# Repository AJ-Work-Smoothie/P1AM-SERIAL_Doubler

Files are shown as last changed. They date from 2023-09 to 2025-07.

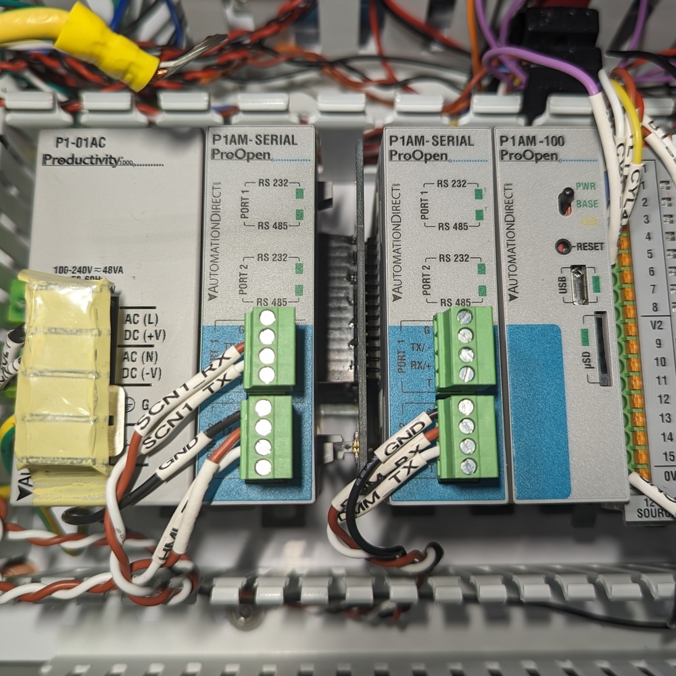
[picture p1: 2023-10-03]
img/Assy.jpg

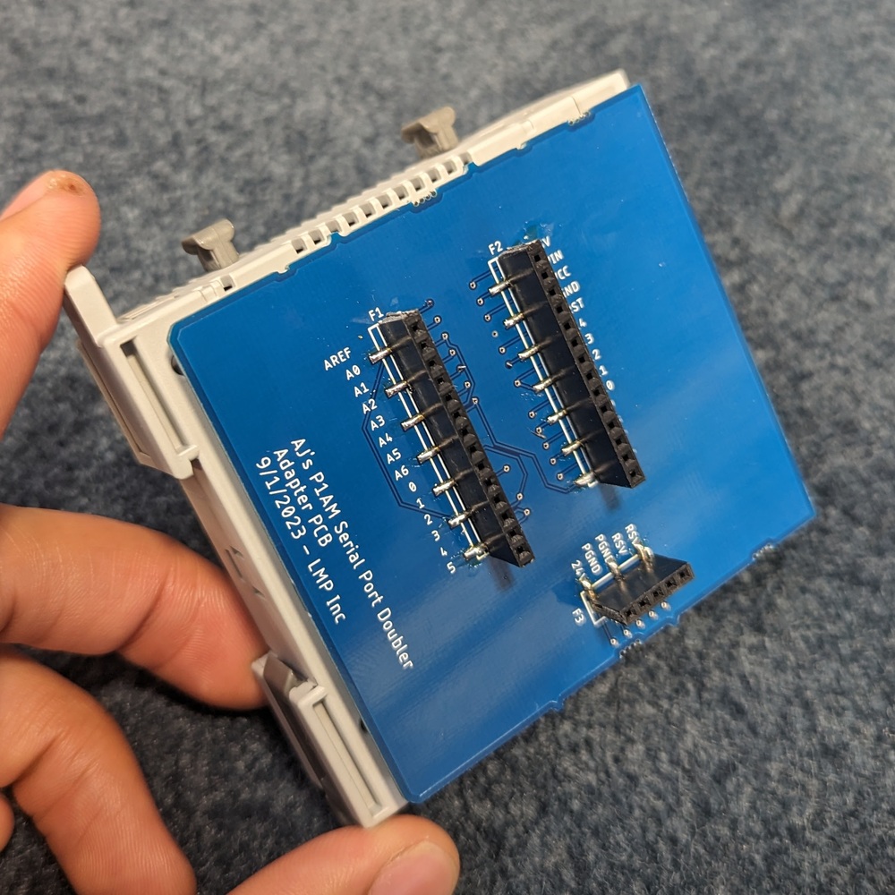
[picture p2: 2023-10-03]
img/Stacked.jpg

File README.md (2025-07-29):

# P1AM-SERIAL Doubler

Sometimes you just need more serial ports! Between modbus, SCPI, ASCII, and the hundred other protocols that work via RS232, sometimes you just can't combine different protocols and need more physical ports. Fear no more! I've done all of the heavy lifting for you. I've designed a circuit board and modified the code for this library to enable to usage of another P1AM-Serial module expanding the amount of ports from 2 to 4! See the wiki for photos.

### Under the Hood:
At its core, the P1AM is a SAMD21G18, which is the same IC that runs the Arduino Zero. If you check into the documentation for the SAMD21, you'll see that is has 6 "sercom" ports. In other words, it has 6 different ports that are configurable to be GPIO pins, UART, I2C, or SPI pins. What I've done is enabled an unsused port, and hijacked the I2C port and reconfigured it to be a serial UART port for us. All of this might sound quite scary, and honestly, it is. Good news is you can skip all the technical and get right to it if you don't need additional information.

Sercom0 is being used for I2C, so we're gonna hijack that, and Sercom4 is completely free. In order to remap these, we have to access the variant.h & variant.cpp board files of the P1AM. The new mappings are as shown:

|  Sercom#/[Pad#]  |  Arduino Port  |  DigitalPin  |  PriorFunc  | NewFunc |
|:---:|:---:|:---:|:---:|:---:|
|  Sercom0/[P0]    | PortA8  |    D11     | SDA |  Serial3 TX  |
|  Sercom0/[P1]    | PortA9  |    D12     | SCL |  Serial3 RX  |
|  Sercom4/[P2]    | PortB10  |    D4      | N/A |  Serial4 TX  |
|  Sercom4/[P3]    | PortB11  |    D5      | N/A |  Serial4 RX  |

All of these definitions are updated in the variants.h & .cpp accordingly. Please note, **I2C will no longer function, and the only free available pin on the module is Pin #7.** We are using all of the available expansion pins for enabling the use of the second P1AM-Serial module.

## Adapter Assembly and Installation: 

**For pictures and more information see this repository's wiki.** The adapter board files are in this repository under "hardware." Within that folder, there are DXF board outlines, GERBER files, Eagle files, and Fusion360 files. PCBs can be ordered very cheaply from places like JLCpcb or PCBWay for less than $20. Obviously through-hole pin headers couldn't be use as the pins connections needed to be rearranged for the secondary module. So "splayed leg" 2.54mm pitch pin headers were used instead. The "splayed leg" male pin headers are available for purchase from Digikey, manufacturer part # M20-8771042, Digikey part # 952-3263-ND. The female pin headers are just your normal headers with the pins splayed out manually with a pair of pliers. Make sure the female headers go on the side of the PCB with the text. It only takes a minute or two to do. After soldering the board up, simply plug the adapter into the side of the P1AM-Serial just like it's another module. Then plug the secondary P1AM-Serial module into the other side. 

## Usage

**To use the doubler, you must install my version of the P1AM library & update variants.h & .cpp. Follow the steps below**

1) Locate your Arduino libary location, and remove the P1AM & P1AM-Serial libraries
2) Download my libaries from this github, P1AM_Doubler & P1AM-Serial_Doubler, and put them in your Arduino library location
3) The variants.cpp & variants.h needs to be updated. Locate those by following this path: C:\Users\YOUR_USER_NAME\AppData\Local\Arduino15\packages\P1AM-100\hardware\samd\1.6.21\variants\P1AM-100
4) In that folder, replace the variants.h & variants.cpp with the ones from my P1AM-Serial_Doubler library - they are in the root directory. 

>NOTE: RS485 was NOT tested, only RS232 on the additional two ports. Unfortunately I don't have a way to test the RS485, but I added all the support in the code for it, so it should work :)

**The code snippets below require the P1AM-Serial_Doubler library. Use of the P1AM-Serial_Doubler library requires version 1.6.21 or greater of the P1AM-100 in the Arduino boards manager.**  

When using the P1AM Serial with a custom protocol, i.e. writing data directly to the port, use the function below that corresponds to the port and mode you are using to configure the port. Baudrate and other settings can be configured the same way as the standard Arduino Serial library. For a list of all configuration options [click here](https://www.arduino.cc/reference/en/language/functions/communication/serial/begin/).

-   **PORT1_RS485_BEGIN()**
-   **PORT1_RS232_BEGIN()**
-   **PORT2_RS485_BEGIN()**
-   **PORT2_RS232_BEGIN()**
-   **PORT3_RS485_BEGIN()**
-   **PORT3_RS232_BEGIN()**
-   **PORT4_RS485_BEGIN()**
-   **PORT4_RS232_BEGIN()**

Once the port is configured, use the `Port1`, `Port2`, `Port3`, & `Port4` objects to interact with the ports. Of course `Port3` is the first port on the second serial module, and `Port4` is the second port on the second serial module. 

```
// Configure both ports for RS485 at 9600 baud, 8 data bits, no parity, 1 stop bit
PORT1_RS485_BEGIN(9600, SERIAL_8N1);
PORT2_RS485_BEGIN(9600);// 8N1 is the default setting
PORT3_RS232_BEGIN(115200, SERIAL_8N1);  
PORT4_RS232_BEGIN(115200, SERIAL_8N1);

// Start RS485 transmission
Port1.beginTransmission();
Port2.beginTransmission();
Port3.beginTransmission();
Port4.beginTransmission();

// Use Ports 1-4 to write to the ports
Port1.write("Hello World 1\r\n");
Port2.write("Hello World 2\r\n");
Port3.write("Hello World 3\r\n");
Port4.write("Hello World 4\r\n");
```

Additionally, you can use the standard `Serial1`, `Serial2`, `Serial3`, & `Serial4` objects to interact with the ports, however when doing so you cannot use any RS485 functions such as `beginTransmission()` or `endTransmission()`.

```
// Configure all ports for RS232 at 115200 baud, 8 data bits, even parity, 1 stop bit
PORT1_RS232_BEGIN(115200, SERIAL_8E1);
PORT2_RS232_BEGIN(115200, SERIAL_8E1);
PORT3_RS232_BEGIN(115200, SERIAL_8E1);
PORT4_RS232_BEGIN(115200, SERIAL_8E1);

// RS232 does not require beginTransmission()

// Use Serial1 and Serial2 to write to the ports
Serial1.write("Hello World 1\r\n");
Serial2.write("Hello World 2\r\n");
Serial3.write("Hello World 3\r\n");
Serial4.write("Hello World 4\r\n");
```

When using the P1AM Serial with a library that has its own begin() function, i.e. ArduinoModbus, manually configure the mode of the ports with `serial_port_config()` **before** calling the library's begin() function.

```
#include <ArduinoRS485.h>
#include <ArduinoModbus.h>
#include <P1AM_Serial.h>

ModbusRTUClientClass rtu_client(Port1); // Create modbus client on port 1

void setup() {

    serial_port_config(1, RS232_MODE); // Set port 1 to RS232 prior to starting modbus client

    rtu_client.begin(115200); // Start modbus client on port 1
}
```

## Default Pin Usage

| Pins  |  Port    | Function  | 
|:-----:|:---:|:---:|
|  14   |  Port 1  |    TX     | 
|  13   |  Port 1  |    RX     | 
|  A6   |  Port 1  |RS485 DE/RE| 
|  3    |  Port 1  |RS232/RS485 Select| 
|  0    |  Port 2  |    TX     | 
|  1    |  Port 2  |    RX     | 
|  6    |  Port 2  |RS485 DE/RE| 
|  2    |  Port 2  |RS232/RS485 Select| 

## Addtional Pin Usage

| Pins  |  Port    | Function  | 
|:-----:|:---:|:---:|
|  11   |  Port 3  |    TX     | 
|  12   |  Port 3  |    RX     | 
|  A1   |  Port 3  |RS485 DE/RE| 
|  A0   |  Port 3  |RS232/RS485 Select| 
|  4    |  Port 4  |    TX     | 
|  5    |  Port 4  |    RX     | 
|  A5   |  Port 4  |RS485 DE/RE| 
|  A2   |  Port 4  |RS232/RS485 Select|

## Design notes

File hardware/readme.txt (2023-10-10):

The male "splayed" pins can be found here: 

Digikey Part# 952-3263-ND
Manufacterer Part# M20-8771042

The female pins are just the typical 2.54mm pitch female pin headers with the pins manually "splayed" as they don't sell female headers like that. 

The file in the the RETIRED folder have been tested, and they WORK. However, the board dimension DXFs have since been updated to better fit into the proto module. I created a new a new eagle .sch & .brd & GERBERs to reflect these new changes, but they have not been physically tested yet! They **SHOULD** work but not having physical proof, I'm going to keep the retired ones in until I order the new boards.

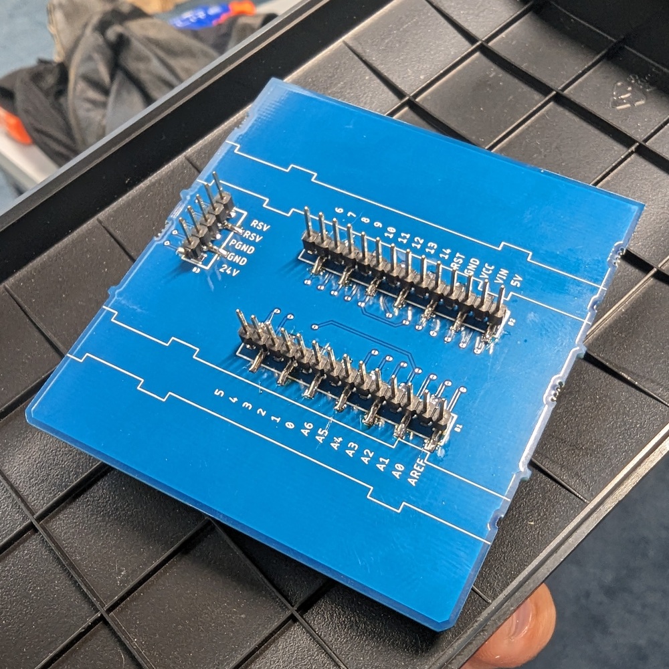
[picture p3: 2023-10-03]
img/Back.jpg

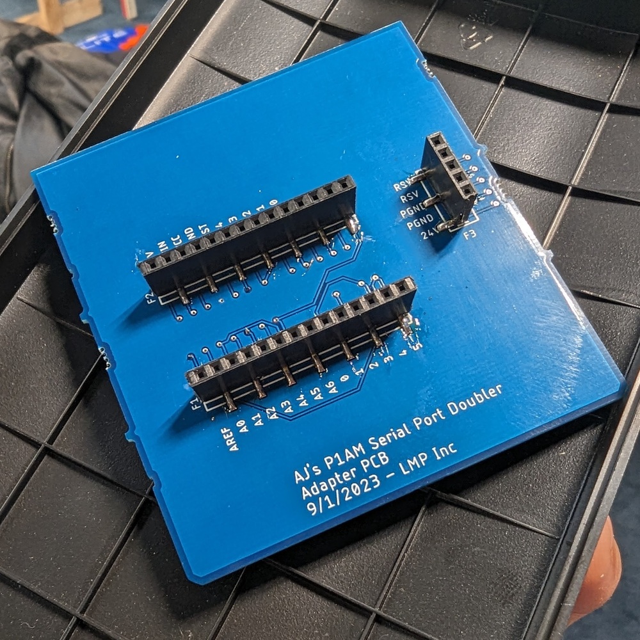
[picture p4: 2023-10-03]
img/Front.jpg

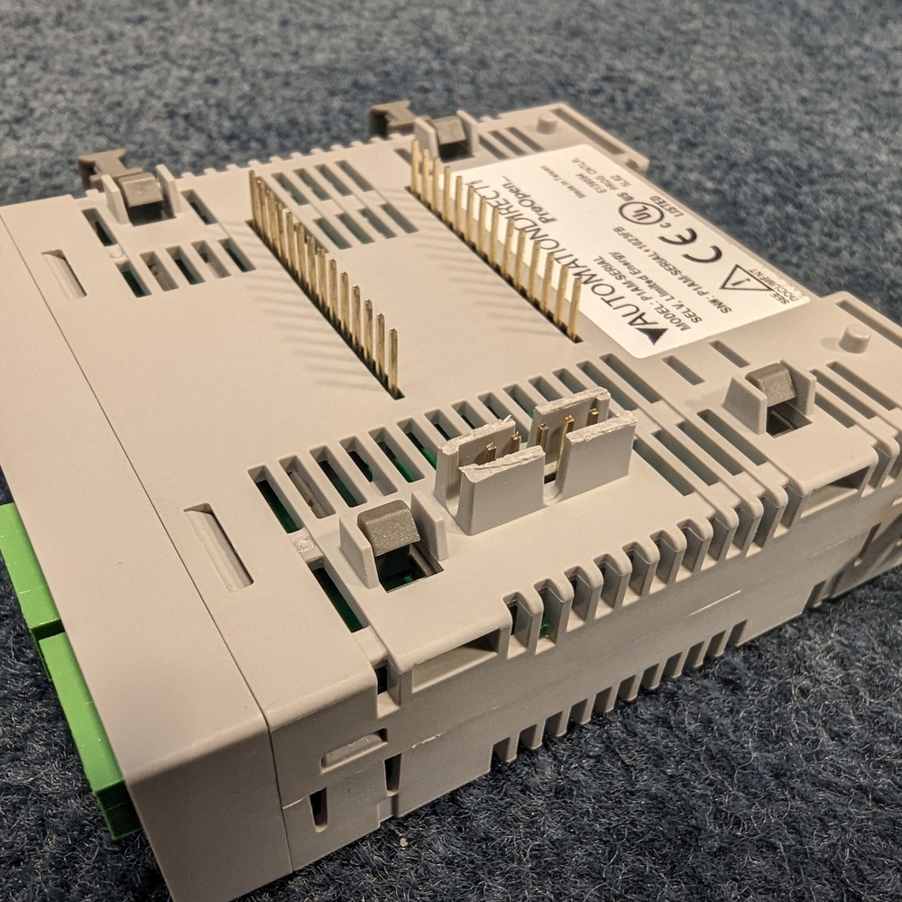
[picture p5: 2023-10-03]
img/shaves.jpg

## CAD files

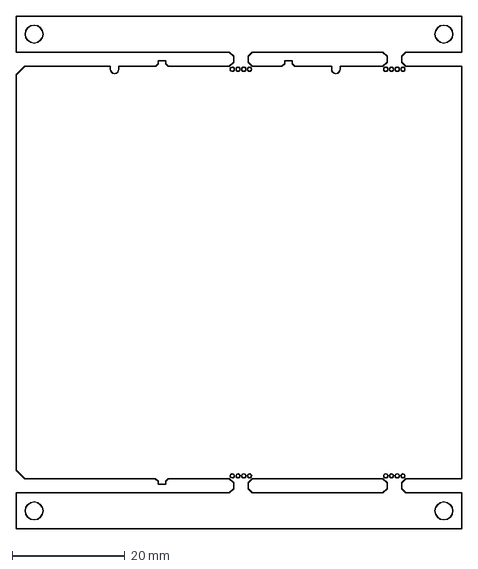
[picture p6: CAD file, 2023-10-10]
hardware/DXFs/P1AM_Proto_Board_Outline.dxf
78.9 x 90.8 mm

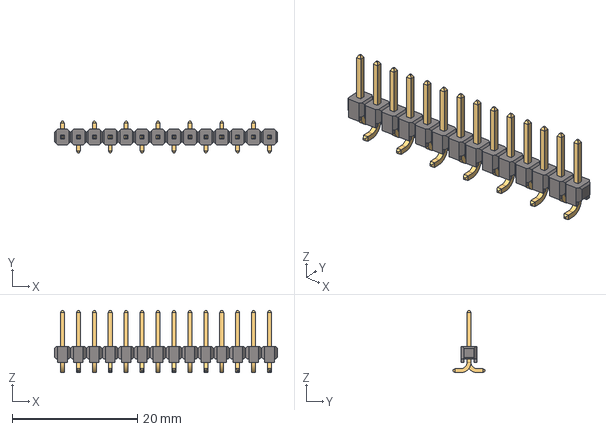
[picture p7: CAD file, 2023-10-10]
hardware/STEPs/2.54_14P_SMD_HDR.step
35.6 x 5.08 x 9.93 mm

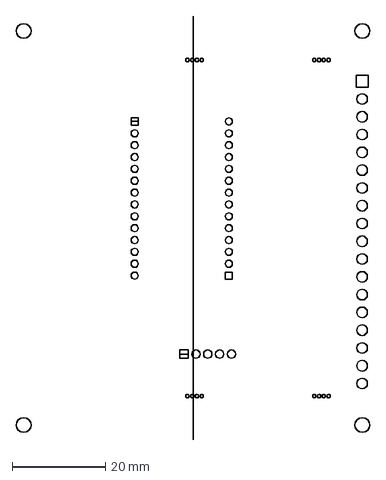
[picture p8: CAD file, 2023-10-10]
hardware/DXFs/P1AM_Proto_Board_Drill_Outlines.dxf
75.7 x 90.8 mm

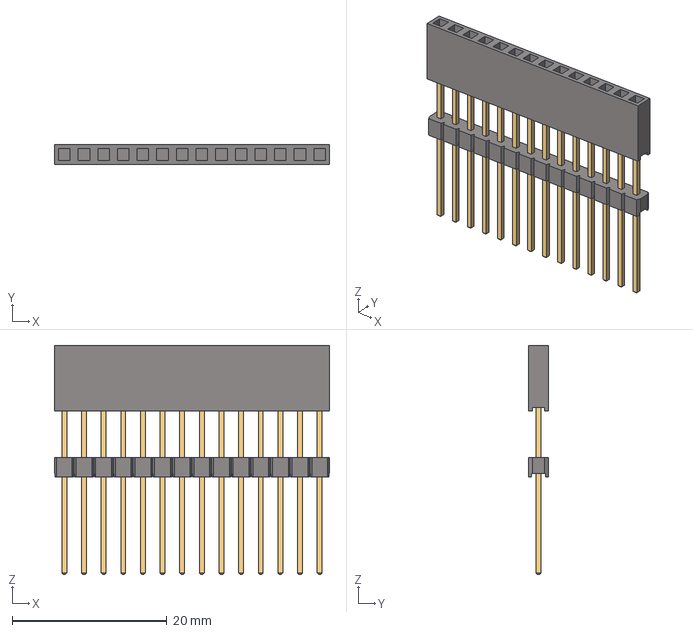
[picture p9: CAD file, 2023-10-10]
hardware/STEPs/2.54_14P_STACKABLE_HDR.step
35.6 x 2.54 x 29.6 mm

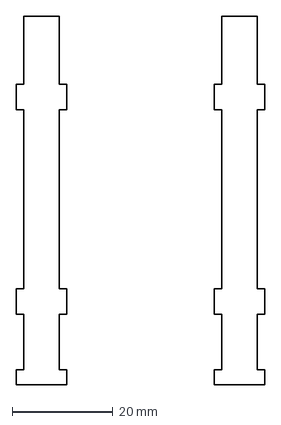
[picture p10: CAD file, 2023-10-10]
hardware/DXFs/P1AM_Proto_Board_bPlace.dxf
49.2 x 73.0 mm

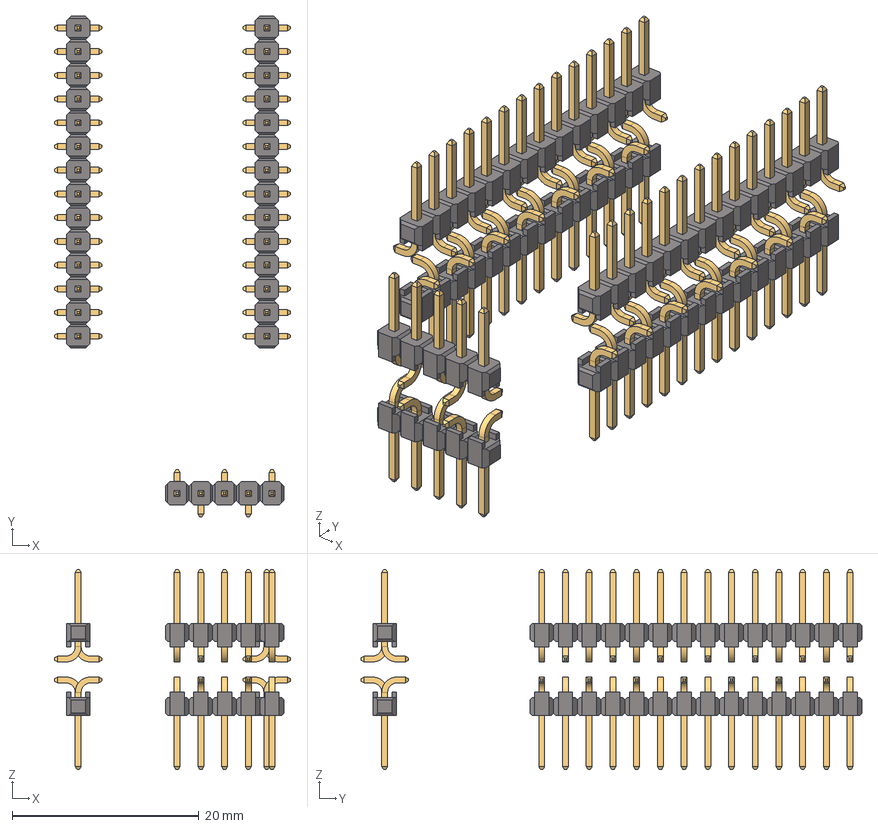
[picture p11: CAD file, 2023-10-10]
hardware/STEPs/P1AM_Proto_SMD_HEADERS.step
25.3 x 53.6 x 21.5 mm
2.54_SMD_PH_14 x 4
2.54_SMD_PH_5 x 2

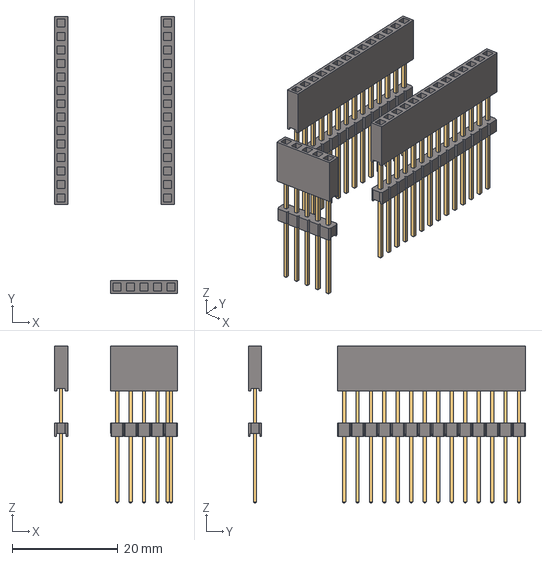
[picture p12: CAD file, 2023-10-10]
hardware/STEPs/P1AM_Proto_Long_Headers.step
23.3 x 52.4 x 29.6 mm
2.54 Extra Long Stackable x 2
2.54 Extra Long Stackable 5p

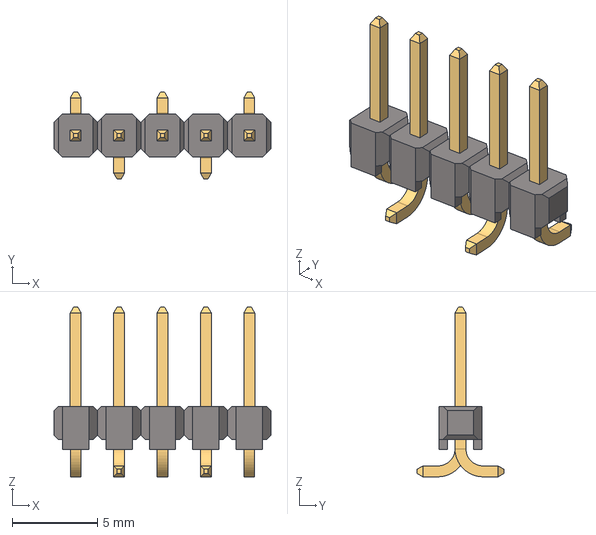
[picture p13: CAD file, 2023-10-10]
hardware/STEPs/2.54_5P_SMD_HDR.step
12.7 x 5.08 x 9.93 mm

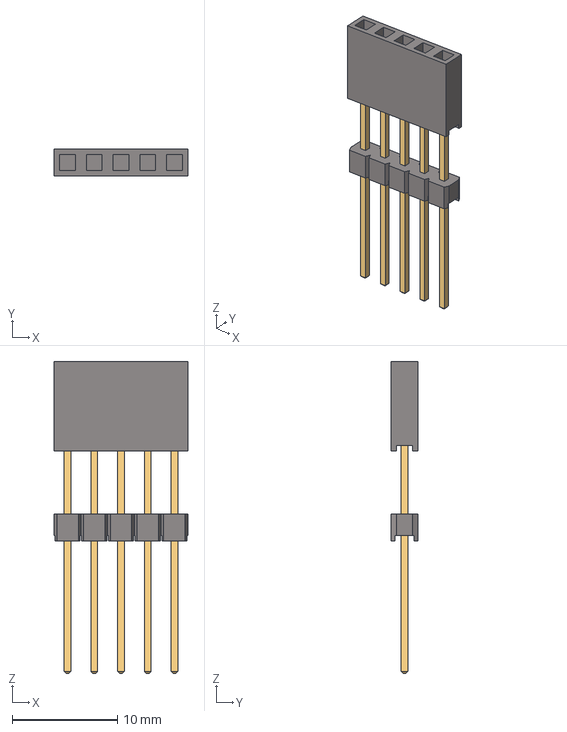
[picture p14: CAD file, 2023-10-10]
hardware/STEPs/2.54_5P_STACKABLE_HDR.step
12.7 x 2.54 x 29.6 mm

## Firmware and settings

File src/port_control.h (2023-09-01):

/*
MIT License

Copyright (c) 2023 FACTS Engineering, LLC

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
*/

#ifndef port_control_h
#define port_control_h

#include "Arduino.h"
#include "RS485.h"

#ifndef PORT1_SERIAL
#define PORT1_SERIAL Serial1
#define PORT1_MODE_PIN	3
#define PORT1_TX_MINUS_PIN	14
#define PORT1_RX_PLUS_PIN 13
#define PORT1_DEFAULT_DE_PIN	A6
#define PORT1_DEFAULT_RE_PIN	PORT1_DEFAULT_DE_PIN
#endif

#ifndef PORT2_SERIAL
#define PORT2_SERIAL Serial2
#define PORT2_MODE_PIN	2
#define PORT2_TX_MINUS_PIN	0
#define PORT2_RX_PLUS_PIN 1
#define PORT2_DEFAULT_DE_PIN	6
#define PORT2_DEFAULT_RE_PIN	PORT2_DEFAULT_DE_PIN
#endif

/////////////////////////////////adding new ports
#ifndef PORT3_SERIAL
#define PORT3_SERIAL Serial3
#define PORT3_MODE_PIN	A0
#define PORT3_TX_MINUS_PIN	11
#define PORT3_RX_PLUS_PIN 12
#define PORT3_DEFAULT_DE_PIN	A1
#define PORT3_DEFAULT_RE_PIN	PORT3_DEFAULT_DE_PIN
#endif

#ifndef PORT4_SERIAL
#define PORT4_SERIAL Serial4
#define PORT4_MODE_PIN	A2
#define PORT4_TX_MINUS_PIN	4
#define PORT4_RX_PLUS_PIN 5
#define PORT4_DEFAULT_DE_PIN	A5
#define PORT4_DEFAULT_RE_PIN	PORT4_DEFAULT_DE_PIN
#endif
///////////////////////////////////////////

#define CTS_PIN PORT2_RX_PLUS_PIN
#define RTS_PIN PORT2_TX_MINUS_PIN

#define RS485_MODE 0
#define RS232_MODE 1


int serial_port_config(int port, int mode);	//Set single port mode
void p1am_serial_init();
int start_handshake(int timeout = 1000, int rts = RTS_PIN, int cts = CTS_PIN);
void set_rts(int rts = RTS_PIN);
void clear_rts(int rts = RTS_PIN);
int read_cts(int cts = CTS_PIN);

extern RS485Class RS485;
#define Port1 RS485
#define Port1_RS485 RS485
#define Port1_RS232 PORT1_SERIAL

extern RS485Class Port2;
#define Port2_RS485 Port2
#define Port2_RS232 PORT2_SERIAL

extern RS485Class Port3;
#define Port3_RS485 Port3
#define Port3_RS232 PORT3_SERIAL

extern RS485Class Port4;
#define Port4_RS485 Port4
#define Port4_RS232 PORT4_SERIAL


// Begin functions defined with macros so 232 options can be used in 485 only libraries
// Configures 485 ports to default to receving
#define PORT1_RS485_BEGIN(...) {   \
        serial_port_config(1, RS485_MODE); \
        Port1.begin(__VA_ARGS__);    \
        Port1.endTransmission();    \
    }

#define PORT1_RS232_BEGIN(...) {   \
        serial_port_config(1, RS232_MODE); \
        Port1.begin(__VA_ARGS__);    \
        Port1.beginTransmission();    \
    }

#define PORT2_RS485_BEGIN(...) {   \
        serial_port_config(2, RS485_MODE); \
        Port2.begin(__VA_ARGS__);    \
        Port2.endTransmission();    \
    }

#define PORT2_RS232_BEGIN(...) {   \
        serial_port_config(2, RS232_MODE); \
        Port2.begin(__VA_ARGS__);    \
        Port2.beginTransmission();    \
    }

/////////////////////////////Adding
#define PORT3_RS485_BEGIN(...) {   \
        serial_port_config(3, RS485_MODE); \
        Port3.begin(__VA_ARGS__);    \
        Port3.endTransmission();    \
    }

#define PORT3_RS232_BEGIN(...) {   \
        serial_port_config(3, RS232_MODE); \
        Port3.begin(__VA_ARGS__);    \
        Port3.beginTransmission();    \
    }

#define PORT4_RS485_BEGIN(...) {   \
        serial_port_config(4, RS485_MODE); \
        Port4.begin(__VA_ARGS__);    \
        Port4.endTransmission();    \
    }

#define PORT4_RS232_BEGIN(...) {   \
        serial_port_config(4, RS232_MODE); \
        Port4.begin(__VA_ARGS__);    \
        Port4.beginTransmission();    \
    }

#endif

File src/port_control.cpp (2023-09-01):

/*
MIT License

Copyright (c) 2023 FACTS Engineering, LLC

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
*/

#include "port_control.h"

bool p1am_init = false;

void p1am_serial_init(){
  if (&RS485 != NULL){
    RS485.setPins(PORT1_TX_MINUS_PIN, PORT1_DEFAULT_DE_PIN, PORT1_DEFAULT_RE_PIN); // Overwrite default pins from Arduino library
  }

  p1am_init = true;
}

int serial_port_config(int port, int mode){
    if(!p1am_init){
        p1am_serial_init();
    }

    if (mode == 232) mode = RS232_MODE;
    else if (mode == 485) mode = RS485_MODE;

	if(mode != RS232_MODE && mode != RS485_MODE){
		return -1;
	} 
	else if(mode == RS232_MODE) {
		if(port == 1) {
			pinMode(PORT1_DEFAULT_DE_PIN, INPUT);
            Port1.setPins(PORT1_TX_MINUS_PIN, -1, -1);
            Port1.setDelays(0, 0);
            Port1.beginTransmission(); // Allows for easier imitation of RS485 mode
		} 
		else if(port == 2) {
			pinMode(PORT2_DEFAULT_DE_PIN, INPUT);
            Port2.setPins(PORT2_TX_MINUS_PIN, -1, -1);
            Port2.setDelays(0, 0);
            Port2.beginTransmission();
		}
		else if(port == 3) {
			pinMode(PORT3_DEFAULT_DE_PIN, INPUT);
            Port3.setPins(PORT3_TX_MINUS_PIN, -1, -1);
            Port3.setDelays(0, 0);
            Port3.beginTransmission();
						pinPeripheral(PIN_SERIAL3_RX, PIO_SERCOM); 
						pinPeripheral(PIN_SERIAL3_TX, PIO_SERCOM);		
		}
		else if(port == 4) {
			pinMode(PORT4_DEFAULT_DE_PIN, INPUT);
            Port4.setPins(PORT4_TX_MINUS_PIN, -1, -1);
            Port4.setDelays(0, 0);
            Port4.beginTransmission();
						pinPeripheral(PIN_SERIAL4_RX, PIO_SERCOM_ALT); 
  				  pinPeripheral(PIN_SERIAL4_TX, PIO_SERCOM_ALT);
		}
	}
	
	if(port == 1){
		pinMode(PORT1_MODE_PIN, OUTPUT);
		digitalWrite(PORT1_MODE_PIN, mode);
	}
	else if(port == 2){
		pinMode(PORT2_MODE_PIN, OUTPUT);
		digitalWrite(PORT2_MODE_PIN, mode);
	}
	else if(port == 3){
		pinMode(PORT3_MODE_PIN, OUTPUT);
		digitalWrite(PORT3_MODE_PIN, mode);
	}
	else if(port == 4){
		pinMode(PORT4_MODE_PIN, OUTPUT);
		digitalWrite(PORT4_MODE_PIN, mode);
	}
	else{
		return -2;
	}
	
	return 0;
}	

int start_handshake(int rts, int cts, unsigned long timeout){
	unsigned long start = 0;
	
	set_rts(rts);
	start = millis();
	while(millis() - start > timeout){
		if(digitalRead(cts)){
			return 0;
		}
	}
	
	return -1; //Timed out
}

void clear_rts(int rts){
	pinMode(rts, OUTPUT);
	digitalWrite(rts, LOW);
}

void set_rts(int rts){
	pinMode(rts, OUTPUT);
	digitalWrite(rts, HIGH);
}

int read_cts(int cts){
	pinMode(cts, INPUT);
	return digitalRead(cts);
}

#ifdef PORT2_SERIAL
RS485Class Port2(PORT2_SERIAL, PORT2_TX_MINUS_PIN, PORT2_DEFAULT_DE_PIN, PORT2_DEFAULT_RE_PIN);
#endif

#ifdef PORT3_SERIAL
RS485Class Port3(PORT3_SERIAL, PORT3_TX_MINUS_PIN, PORT3_DEFAULT_DE_PIN, PORT3_DEFAULT_RE_PIN);
#endif

#ifdef PORT4_SERIAL
RS485Class Port4(PORT4_SERIAL, PORT4_TX_MINUS_PIN, PORT4_DEFAULT_DE_PIN, PORT4_DEFAULT_RE_PIN);
#endif

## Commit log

2023-10-10 Adding the NEW updated board outline
    [P1AM_Serial_Adapter_Board.brd, P1AM_Serial_Adapter_Board.sch]
2023-10-10 Merging libraries
    [2.54_14P_SMD_HDR.step, 2.54_14P_STACKABLE_HDR.step, 2.54_5P_SMD_HDR.step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]
